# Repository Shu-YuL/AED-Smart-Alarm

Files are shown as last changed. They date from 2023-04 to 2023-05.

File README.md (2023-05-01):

# AED Smart Alarm

--updated Jan 17, 2023 by Shu-Yu Lin

--updated Feb 14, 2023 by Shu-Yu Lin

--updated Mar 14, 2023 by Shu-Yu Lin

--updated Mar 27, 2023 by Shu-Yu Lin

--updated Apr 4, 2023 by Shu-Yu Lin

--updated Apr 30, 2023 by Shu-Yu Lin

----------------------------------------------------------------

## Demo Video

[![Demo Video](https://lh3.googleusercontent.com/fife/APg5EOZy0qmSeqRbGbYMGeu49TxH5lmIOj3HhFyADLr6qH4S8TAaIJzbBPQnfgN_s-cPjZGFoLVAi6fIpvv_eCJc7_dvCM5OVtgkbksEu1INZQIVRCa6F0s9MO7LJb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)](https://drive.google.com/file/d/1JeJAB9AQrucV8XEORTZ0Mz8k3fBR3jVF/view?usp=sharing "Demo video")

## Introduction

Our project aims to improve upon the current AED monitoring system used by the University of Alberta Emergency Management Team (UAEMT) and University of Alberta Protective Services (UAPS). The current system has issues with delays in receiving alerts and the need for frequent re-authentication. Our new system addresses these issues and provides more advanced notice for time-sensitive alerts, enabling UAPS to respond more quickly in case of a medical emergency.

## Method of Project Approach

Our project consists of three main components. The first component is the alarm, a monitoring device installed inside each AED cabinet and used to detect if the cabinet door opens. The second component is a base station unit installed inside the UAPS office used notify people in the office if any of the alarm monitoring devices inside the AED cabinet are triggered. The third component is a Google Apps Script managed Google Sheets, it processes HTTP requests sent from the base station and the monitoring devices and sends **an email, along	with Telegram and Discord channel announcement message** to UAPS if any of the monitoring devices are triggered.

### Monitoring Device

- Every monitoring device is powered by batteries.
- A door switch sensor is used to detect any motion of the cabinet door.
- The activation of the switch sends a digital signal to wake up and trigger the device.
- The development board used is ESP32-DevKitC V4.
- When the MCU is active, it will try to connect to campus WiFi and sends its MAC address to the Google Sheet through an HTTP GET request.
- The monitoring device will go back to sleep after it receives an acknowledgement from the Google Sheet.

### Base Station

- The base station is powered by a wall outlet power supply that will supply 5V.
- The MCU used for the base station is ESP32-WROOM-32E.
- An 2004 LCD display is mounted on the base station and connected to the MCU via the I²C interface.
- LED bulbs are used and controlled via the MCU's digital output signal. Similarly, a piezoelectric buzzer is also used and controlled via PWM signals from the MCU.
- The base station is to be connected to campus Wifi and pull data from the Google Sheet every 10 seconds through sending an HTTP GET request. It receives an empty message when no monitoring device is triggered. If any of the monitoring devices are triggered, it receives a string showing the location of this monitoring device and then activates buzzer, LED, and also displays alert message on the LCD display.
- Users can interact with the base station with onboard pushbuttons. One pushbutton labeled "Clear" is used to dismiss an alert event, while the other one is used to turn off the buzzer.

### Google Sheet

- Serves as a Web Server and online User Interface for the project
- Manages HTTP Requests and data sent from both the Base Station and the Monitoring Devices
- Provides an paired device list that can be managed by the user
- Provides an Event Log sheet that records all triggering events along with triggered date and time of each event
- Sends notifications through email, Telegram and Discord channel when an event is triggered or cleared
- Sends notifications through email, Telegram and Discord channel when a prospect low battery is detected

The project firmware is developed in C language using ESP-IDF. The Google Sheet is managed using Google Apps Script which the script is developed in JavaScript.

## Usage of this Repository

This repository contains all the code, files such as the hardware design project, PCB layout and 3D models. Please refer to the documentation for instructions on how to set up and use the system.

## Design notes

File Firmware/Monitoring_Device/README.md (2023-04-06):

# Monitoring Device

-- updated March 9, 2023 by Shu-Yu Lin

-- updated March 17, 2023 by Shu-Yu Lin

-- updated April 4, 2023 by Shu-Yu Lin

## Development Progress

### What's ready

- Wifi
- HTTP Client
  - Door switch (currently using a button to simulate triggering behavior) GPIO interrupt (Post device MAC addr to Google Sheet)
- Deep Sleep

### What's left

- None

## How to use

Pull the **```Monitoring_Device```** folder to your local folder and copy and paste these files to your local project folder and build from there.

In **```wifi_include.h```**, the first line ``` #define ... ```, please enter ``` HOME ``` if you are off campus or using on campus **```DevNet```** WiFi, ``` UWS ``` if you are on campus.

Remember to enter your WiFi **```SSID```** and **```Password```** in **```wifi_include.h```** for home internet. Enter your **```CCID```** and **```Password```** in **```UWS_include.h```** for campus internet.

**Only pushes the same files back to the Repository** as other folders are associated with your own PC environment (ex: your ESP-IDF path) which is different from other people's environment.

## Pinout

(ESP32-DevkitC-V4)

### Door Switch (PIN 25)

Button image

Lead 1 - PIN 25 INPUT, PULLDOWN, HIGH level wake up

Lead 2 - 3.3V

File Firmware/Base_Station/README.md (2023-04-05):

# Base Station

-- updated March 1, 2023 by Shu-Yu Lin

-- updated March 17, 2023 by Shu-Yu Lin

-- updated April 4, 2023 by Mohammad Kamal

## Development Progress

### What's ready

- Wifi
- HTTP Client
  - 5 sec recurring timer interrupt (read data from Google Sheet)
  - Clear button GPIO interrupt (remove row 2 in *Triggered_devices* sheet, same as clearing an event)
- LCD Screen
- Buzzer
- Alarm LED

## How to use

Pull the **```Base_Station```** folder to your local folder and copy and paste these files to your local project folder and build from there.

In **```wifi_include.h```**, the first line ``` #define ... ```, please enter ``` HOME ``` if you are off campus or using on campus **```DevNet```** WiFi, ``` UWS ``` if you are on campus.

Remember to enter your WiFi **```SSID```** and **```Password```** in **```wifi_include.h```** for home internet. Enter your **```CCID```** and **```Password```** in **```UWS_include.h```** for campus internet.

**Only pushes the same files back to the Repository** as other folders are associated with your own PC environment (ex: your ESP-IDF path) which is different from other people's enviornment.

## Pinout

(ESP32-DevkitC-V4)

### LCD

PIN 18 - SDA

PIN 19 - SCL

5V     - VCC

GND    - GND

### Clear Button

Button image

Lead 1 - PIN 22 INPUT, PULLDOWN, POS EDGE TRIGGER

Lead 2 - 3.3V

### Buzzer control Button

Lead 1 - PIN 21 INPUT, PULLDOWN, POS EDGE TRIGGER

Lead 2 - 3.3V

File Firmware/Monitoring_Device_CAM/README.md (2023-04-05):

# Monitoring Device with Camera

-- updated March 9, 2023 by Shu-Yu Lin

-- updated March 12, 2023 by Shu-Yu Lin

-- updated March 17, 2023 by Shu-Yu Lin

-- updated April 4, 2023 by Shu-Yu Lin

## Development Progress

### What's ready

- Wifi
- HTTP Client
  - Door switch (currently using a button to simulate triggering behavior) GPIO interrupt (Post device MAC addr to Google Sheet)
- Camera Video Stream Server
- DevNet Access tested

### What's left

- None

## How to use

Pull the **```Monitoring_Device_CAM```** folder to your local folder and copy and paste these files to your local project folder and build from there.

Remember to enter your WiFi **```SSID```** and **```Password```** in **```wifi_include.h```** for home internet or using on campus **```DevNet```** WiFi.

**Only pushes the same files back to the Repository** as other folders are associated with your own PC environment (ex: your ESP-IDF path) which is different from other people's environment.

## Pinout

(ESP32-CAM)

### Door Switch (Currently PIN 13)

Button image

Lead 1 - PIN 13 INPUT, PULLDOWN, POS EDGE TRIGGER

Lead 2 - 3.3V

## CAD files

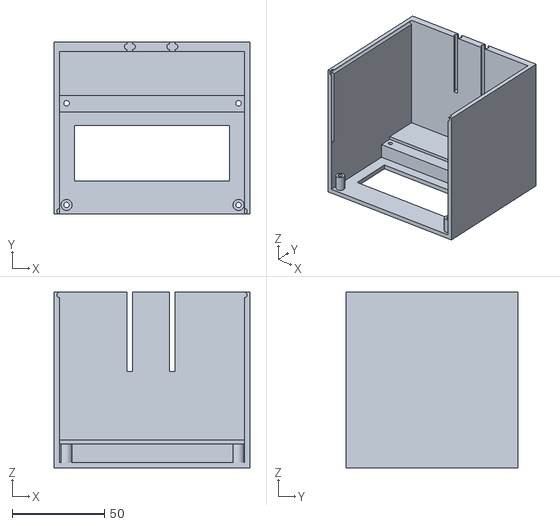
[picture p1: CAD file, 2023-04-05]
Hardware/3D_models/AED_BS_FT_SIDES v15.stl
106.0 x 93.1 x 95.0

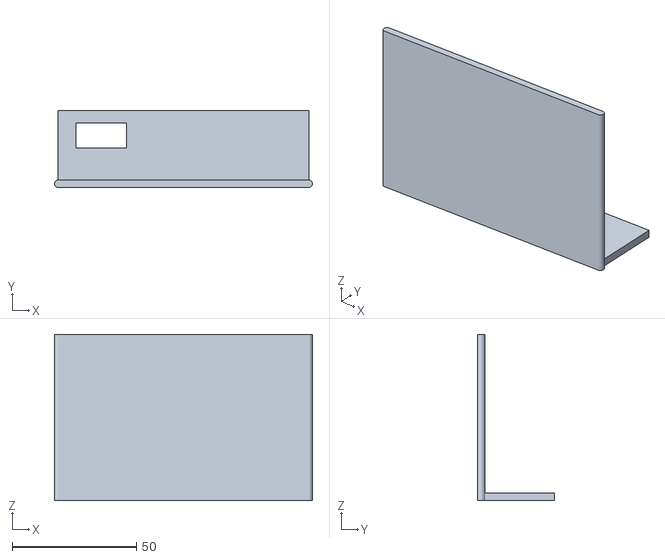
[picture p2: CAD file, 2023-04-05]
Hardware/3D_models/AED_MD_TOP v10.stl
104.0 x 31.0 x 67.0

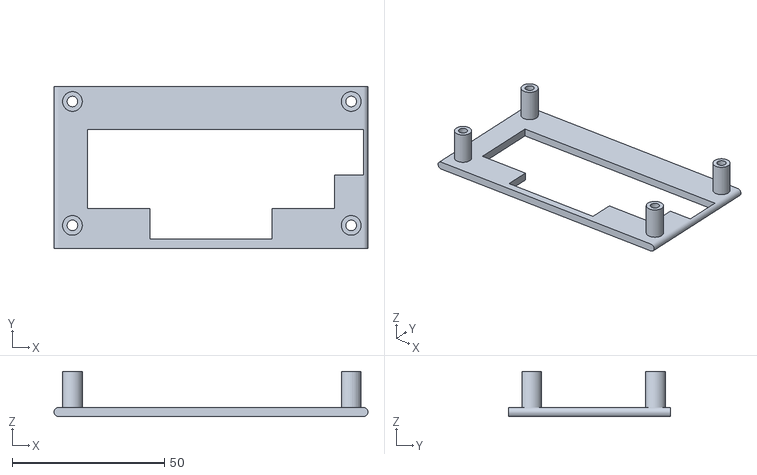
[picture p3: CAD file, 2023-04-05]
Hardware/3D_models/AED_BS_TOP v11.stl
103.0 x 53.0 x 14.8

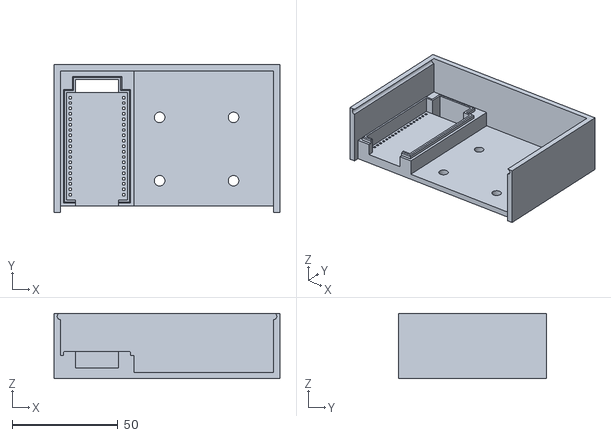
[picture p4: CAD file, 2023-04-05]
Hardware/3D_models/AED_MD_BOT v16.stl
107.0 x 70.0 x 31.0

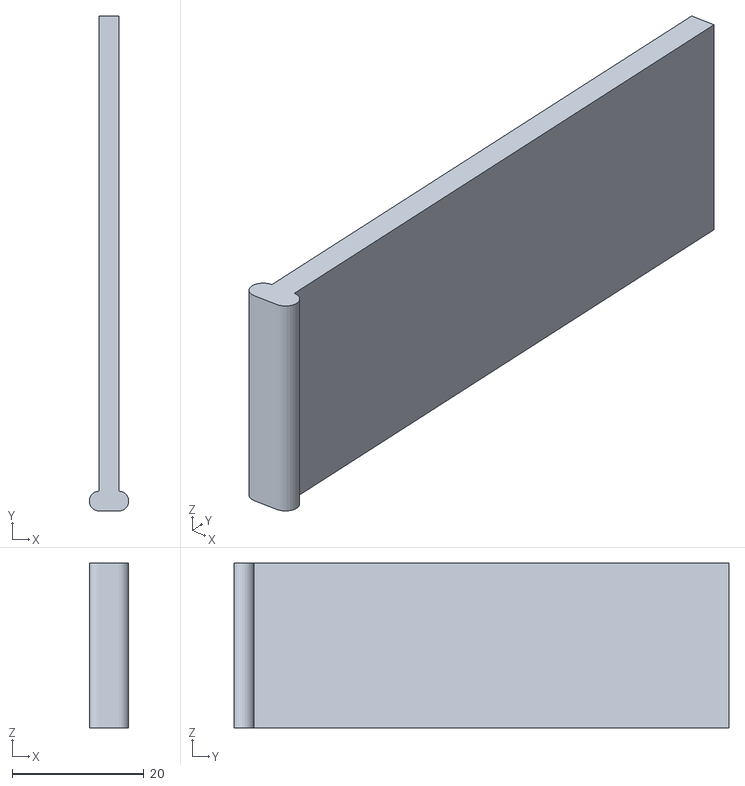
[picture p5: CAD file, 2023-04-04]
Hardware/3D_models/AED_BS_sup v1.stl
5.98 x 75.0 x 25.0

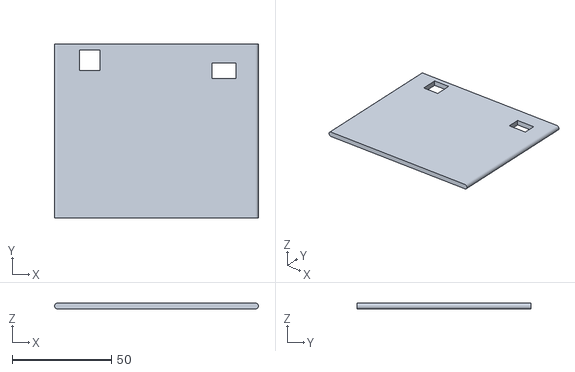
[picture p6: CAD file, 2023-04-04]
Hardware/3D_models/AED_BS_BACK v5.stl
103.0 x 88.0 x 3.00

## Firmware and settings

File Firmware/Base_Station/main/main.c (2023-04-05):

/* Group: 16 AED Smart Alarm - Base Station
 * Module: main
 * Description: This is the main program of our AED Base Station. The purpose of this code is to retrieves the
                triggering device's location (if any) from the web server via HTTP request.
 * Authors: Shu-Yu Lin, Pei-Yu Huang, Mohammad Kamal
 * References:  - Espressif Official API References
 *                  - https://docs.espressif.com/projects/esp-idf/en/latest/esp32/api-reference/index.html
 *                  - https://github.com/espressif/esp-idf/tree/47852846d3e89580ef4da28210b6ffc1cb5eaa9d/examples
 * Revision Information: V.0.0 (First Revision)
 * Date: 17/March/2023
 * Copyright: N/A
 * Functions: - LCD_init()
              - LCD_home()
              - LCD_clearScreen()
              - LCD_Secured()
              - setup_nvs(void)
              - connect_wifi()
              - initialize_wifi()
              - check_wifi()
              - Clear_button()
              - buzzer_pwm_init()
              - Buzzer_button_config()
*/

#include "wifi_include.h"
#include "UWS_include.h"
#include "HD44780.h"
#include "base_station.h"
#include "Buzzer_include.h"

/* Defining TAG name for debugging */
static const char *TAG = "Main";


/*------------------------------------------
Function Name: setup_nvs()
Description: Initializes and clears the NVS in the ESP32.
Input: N/A
Output: N/A
Variables Affected: N/A
-------------------------------------------*/
void setup_nvs(void) {
    esp_err_t ret = nvs_flash_init();
    if (ret == ESP_ERR_NVS_NO_FREE_PAGES || ret == ESP_ERR_NVS_NEW_VERSION_FOUND) {
      ESP_ERROR_CHECK(nvs_flash_erase());
      ret = nvs_flash_init();
    }
    ESP_ERROR_CHECK(ret);
}

#ifdef UWS

/* FreeRTOS event group to signal when we are connected & ready to make a request */
static EventGroupHandle_t wifi_event_group;

/* esp netif object representing the WIFI station */
static esp_netif_t *sta_netif = NULL;


const int wifi_connected = BIT0; //flag indicating whether or not we are connnected to wifi


/*------------------------------------------
Function Name: wifi_event_handler()
Description: Event handler function for using WPA2 WiFi networks like UWS. Calls esp_wifi_connect() 
             to connect to WiFi if we start WiFi or WiFi disconnects.
Input: esp_event_base_t event, int32_t event_id, event_data
Output: N/A
Variables Affected: wifi_connected
-------------------------------------------*/

static void wifi_event_handler(void* arg, esp_event_base_t event, int32_t event_id, void* event_data) {
    
    if (event == WIFI_EVENT && event_id == WIFI_EVENT_STA_START) {
        esp_wifi_connect();
    } else if (event == WIFI_EVENT && event_id == WIFI_EVENT_STA_DISCONNECTED) {
        esp_wifi_connect();
        xEventGroupClearBits(wifi_event_group, wifi_connected);
    } else if (event == IP_EVENT && event_id == IP_EVENT_STA_GOT_IP) {
        xEventGroupSetBits(wifi_event_group, wifi_connected);
    }
}

/*------------------------------------------
Function Name: initialize_wifi()
Description: Sets up ESP32 as a WiFi station and configures parameters such as ssid and password, and starts WiFi.
             Used for WPA2 networks like UWS.
Input: N/A
Output: N/A
Variables Affected: N/A
-------------------------------------------*/
/* sets up wifi parameters and starts attempt to connect to wifi  */
static void initialize_wifi(void) {

    ESP_ERROR_CHECK(esp_netif_init());
    wifi_event_group = xEventGroupCreate();
    ESP_ERROR_CHECK(esp_event_loop_create_default());
    sta_netif = esp_netif_create_default_wifi_sta();
    assert(sta_netif);

    wifi_init_config_t cfg = WIFI_INIT_CONFIG_DEFAULT();
    ESP_ERROR_CHECK( esp_wifi_init(&cfg) );
    ESP_ERROR_CHECK( esp_event_handler_register(WIFI_EVENT, ESP_EVENT_ANY_ID, &wifi_event_handler, NULL) );
    ESP_ERROR_CHECK( esp_event_handler_register(IP_EVENT, IP_EVENT_STA_GOT_IP, &wifi_event_handler, NULL) );
    ESP_ERROR_CHECK( esp_wifi_set_storage(WIFI_STORAGE_RAM) );
    
    wifi_config_t wifi_config = {.sta = {.ssid = WIFI_SSID,},};

    ESP_LOGI(TAG, "Setting SSID to %s...", wifi_config.sta.ssid);
    ESP_ERROR_CHECK( esp_wifi_set_mode(WIFI_MODE_STA) );
    ESP_ERROR_CHECK( esp_wifi_set_config(WIFI_IF_STA, &wifi_config) );
    ESP_ERROR_CHECK( esp_wifi_sta_wpa2_ent_set_identity((uint8_t *)WIFI_EAP_ID, strlen(WIFI_EAP_ID)) );


    ESP_ERROR_CHECK( esp_wifi_sta_wpa2_ent_set_username((uint8_t *)WIFI_EAP_USERNAME, strlen(WIFI_EAP_USERNAME)) );
    ESP_ERROR_CHECK( esp_wifi_sta_wpa2_ent_set_password((uint8_t *)WIFI_EAP_PASSWORD, strlen(WIFI_EAP_PASSWORD)) );


    ESP_ERROR_CHECK( esp_wifi_sta_wpa2_ent_enable() );
    ESP_ERROR_CHECK( esp_wifi_start() );
}

/*------------------------------------------
Function Name: check_wifi()
Description: Checks WiFi connection status and retrieves details such as ssid, ip address and mac address if connected to a WiFi network.
Input: N/A
Output: N/A
Variables Affected: N/A
-------------------------------------------*/
static void check_wifi(void)
{
    esp_netif_ip_info_t ip_info;
    memset(&ip_info, 0, sizeof(esp_netif_ip_info_t));
    vTaskDelay(2000 / portTICK_PERIOD_MS);

    wifi_ap_record_t ap_info;
    esp_err_t connection_status = ESP_ERR_WIFI_NOT_CONNECT;
    esp_netif_get_ip_info(sta_netif, &ip_info);

    while ((ip_info.ip.addr) == 0) { // keep checking connection status and waiting until ip address received, indicating a successful connection 
        vTaskDelay(2000 / portTICK_PERIOD_MS);
        connection_status = esp_wifi_sta_get_ap_info(&ap_info);
        esp_netif_get_ip_info(sta_netif, &ip_info);
    }

    if (esp_netif_get_ip_info(sta_netif, &ip_info) == ESP_OK) { // print wifi connection parameters 
        ESP_LOGI(TAG, "-----------------------");
        ESP_LOGI(TAG, "SSID: %s", ap_info.ssid);
        ESP_LOGI(TAG, "IP Address: "IPSTR, IP2STR(&ip_info.ip));
        //ESP_LOGI(TAG, "MAC Address: %X:%X:%X:%X:%X:%X:" ap_info.bssid[0],ap_info.bssid[1], ap_info.bssid[2], ap_info.bssid[3], ap_info.bssid[4], ap_info.bssid[5]);
        ESP_LOGI(TAG, "-----------------------");
    }

    return;
}

#endif

/*------------------------------------------
Function Name: app_main()
Description: Main program that sets up the base station. 
            Sets up the LCD and buttons, creates a 5s timer interrupt to continously request data from Google Apps web server and starts WiFi.
Input: N/A
Output: N/A
Variables Affected: N/A
-------------------------------------------*/
void app_main(void)
{
    LCD_init(LCD_ADDR, SDA_PIN, SCL_PIN, LCD_COLS, LCD_ROWS); /* Initializing LCD parameters */

    LCD_home(); /* This function is called before we want to output anything to the screen */
    LCD_clearScreen(); /* This function is called to clear the current screen */
    LCD_Secured();

    setup_nvs();

    #ifdef HOME // if using wifi off campus or on campus DevNet
    connect_wifi();
    #endif

    #ifdef UWS // if using UWS wifi
    initialize_wifi();
    check_wifi();
    #endif

    /* recurring 5s timer interrupt task for pulling data from web server */
    TimerHandle_t timer = xTimerCreate("timer", pdMS_TO_TICKS(TIMER_PERIOD_MS), pdTRUE, 0, timer_callback);
    xTimerStart(timer, 0); // start the timer
    
    /* Clear button GPIO interrupt setup */
    Clear_button();

    /* Buzzer output setup */
    buzzer_pwm_init();
    // Set duty to 50%
    ESP_ERROR_CHECK(ledc_set_duty(LEDC_MODE, LEDC_CHANNEL, LEDC_DUTY));
    /* Buzzer button GPIO interrupt setup */
    Buzzer_button_config();
}

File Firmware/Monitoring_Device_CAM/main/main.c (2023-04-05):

/* Group: 16 AED Smart Alarm - Monitoring Device ver.CAM
 * Module: main
 * Description: This is the main program of our AED Monitoring Device with Camera. The purpose of this code is to send the
                device's MAC and IP address to the web server via HTTP request.
 * Authors: Pei-Yu Huang, Shu-Yu Lin, Mohammad Kamal
 * References:  - Espressif Official API References
 *                  - https://docs.espressif.com/projects/esp-idf/en/latest/esp32/api-reference/index.html
 *                  - https://github.com/espressif/esp-idf/tree/47852846d3e89580ef4da28210b6ffc1cb5eaa9d/examples
 *              - ESP32 Tutorials (admin@esp32tutorials.com)
 *                  - https://esp32tutorials.com/esp32-esp-idf-send-messages-whatsapp/
 *                  - https://esp32tutorials.com/esp32-cam-esp-idf-live-streaming-web-server/#more-2787
 * Revision Information: V.0.0 (First Revision)
 * Date: 12/March/2023
 * Copyright: N/A
 * Functions: - setup_nvs(void)
              - connect_wifi()
              - get_MAC()
              - setup_server()
              - init_camera()
*/
#include "monitoring_device.h"
#include "wifi_include.h"
#include "camera_include.h"
/* Defining TAG name for debugging */
static const char *TAG = "Main";

/*------------------------------------------
Function Name: setup_nvs()
Description: Initializes and clears the NVS in the ESP32.
Input: N/A
Output: N/A
Variables Affected: N/A
-------------------------------------------*/
void setup_nvs(void) {
    //Initializes NVS
    esp_err_t ret = nvs_flash_init();
    if (ret == ESP_ERR_NVS_NO_FREE_PAGES || ret == ESP_ERR_NVS_NEW_VERSION_FOUND) {
      ESP_ERROR_CHECK(nvs_flash_erase());
      ret = nvs_flash_init();
    }
    ESP_ERROR_CHECK(ret);
}

/*------------------------------------------
Function Name: app_main()
Description: Main program that sets up the Monitoring Device. 
Input: N/A
Output: N/A
Variables Affected: N/A
-------------------------------------------*/
void app_main(void)
{
    esp_err_t err;

    setup_nvs();
    connect_wifi();
    
    get_MAC(); /* Function call to get device's MAC address*/
    interrupt_init(); /* Initialize GPIO Interrupt */

    err = init_camera(); /* Function call to setup camera */
    if (err != ESP_OK)
    {
        printf("err: %s\n", esp_err_to_name(err));
        return;
    }
    setup_server(); /* Function call to setup web server */
    ESP_LOGI(TAG, "ESP32 CAM Web Server is up and running\n");
}

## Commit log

2023-02-13 update monitoring device firmware
2023-02-27 fix http client bugs and update URL. Complete MD check http response function.
    [main.c, monitoring_device.c]
2023-03-06 update IO pin selection, UWS function fix
    [main.c]
2023-03-06 update MD http response checker, UWS function fix
    [main.c, monitoring_device.c]
2023-03-09 update main monitoring device code, added deep sleep
2023-03-09 Added CAM version Monitoring device project folder
2023-03-12 update: Added comments to the files related to the both monitoring devices. The wi-fi portion is left to be updated. Mo please add the comments whenever you have time.
2023-03-13 update monitoring device ver.CAM commenting, GS URL, and README.md
2023-03-13 update monitoring device commenting, and GS URL
2023-03-17 update BS buzzer code and GS URL, MD minor changes and GS URL
    [Buzzer_functions.c, Buzzer_include.h, base_station.c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]
2023-03-26 added case 3d models
    [AED_BS_BACK v2.stl, AED_BS_FT_SIDES v3.stl, AED_BS_TOP v4.stl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]
2023-03-28 update case 3D models
    [AED_BS_BACK v2.stl, AED_BS_BACK v4.stl, AED_BS_BOT v13.stl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]
2023-03-31 update case models
    [AED_BS_BOT v13.stl, AED_BS_FT_SIDES v11.stl, AED_BS_FT_SIDES v8.stl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]
2023-04-04 Added LED functionality, improved comments
2023-04-04 Added LED functionality and improved comments,
2023-04-05 Wrap up Firmware. Clean up unused files. Complete comments
    [AED_BS_FT_SIDES v11.stl, AED_BS_FT_SIDES v15.stl, AED_BS_TOP v11.stl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]
2023-04-05 update main README.md
    [0ZCJ0110FF2E.STEP, 10118194-0001LF.step, 382811-8.STEP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]
2023-04-05 remove kicad project
    [0ZCJ0110FF2E.STEP, 10118194-0001LF.step, 382811-8.STEP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]
2023-04-06 fix MD bugs, update GS URL
    [monitoring_device.c]
2023-04-08 minor changes to buzzer button behavior
    [base_station.c]
